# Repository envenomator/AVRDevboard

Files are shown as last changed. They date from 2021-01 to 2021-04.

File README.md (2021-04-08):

I bought the book 'Make: AVR Programming - by Elliot Williams' and soon got fed up breadboarding the experiments.
So I created an PCB-based development board for Atmega328p, with basics like 

8x LED on PB0-7
LDR / Potmeter
Servo header / servo power selector 
Two pushbuttons, one at each INT0/1
I2C header 
Serial header 

Several jumpers, to make optimal use of pins.

Selections via jumpers:
1) Use either crystal or LEDs on PB6/7
2) Use either LDR or Potmeter at PC0
3) Use either Servo or LED at PB1 / T1 16-bit timer OC1A
4) Use either VCC voltage for servo, or seperately supplied voltage

PINs available for
1) I2C
2) Serial GND/TX/RX
3) INT0/INT1

Photo shows an earlier PCB with switched labels. Current gerbers are correct and have been printed correctly at JLCPCB.

Enjoy experimenting!

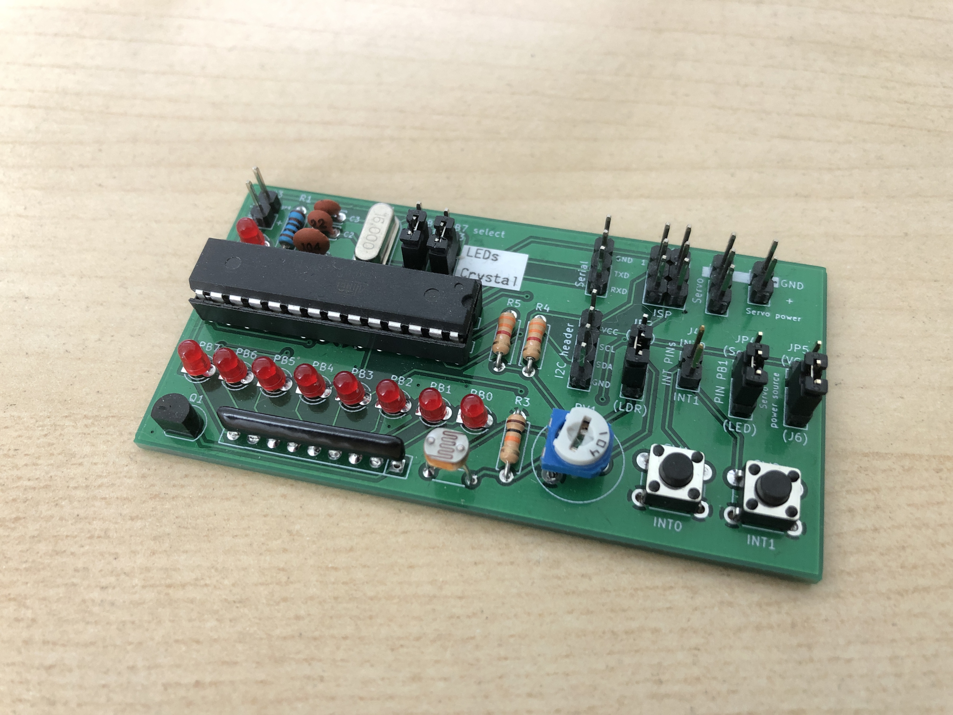
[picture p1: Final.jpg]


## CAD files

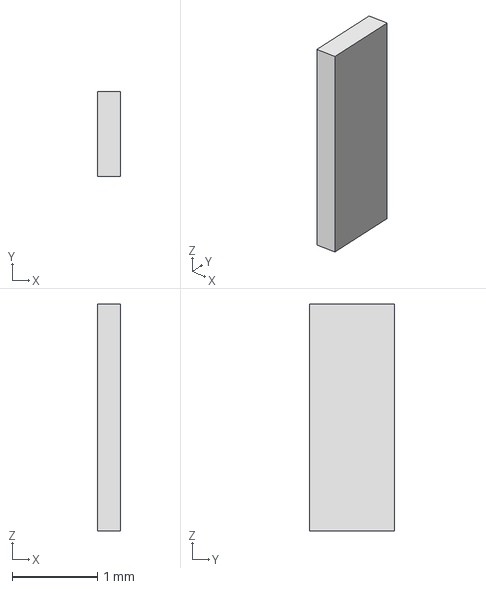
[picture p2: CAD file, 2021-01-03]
eec.models/Texas_Instruments_-_OPA37GP.step
0.27 x 1 x 2.66 mm

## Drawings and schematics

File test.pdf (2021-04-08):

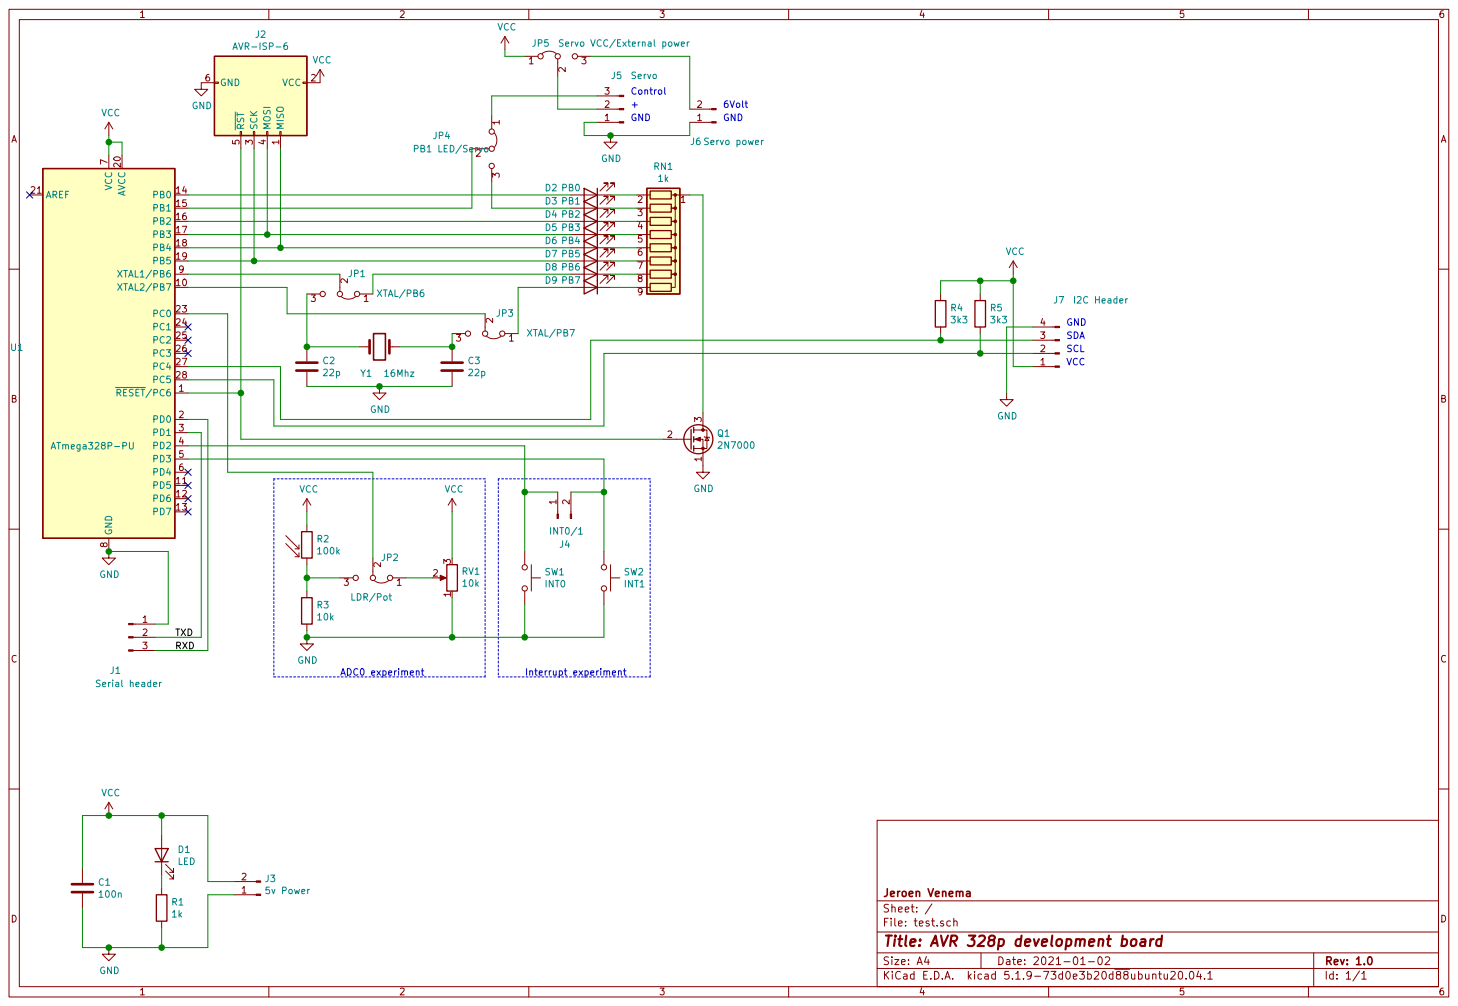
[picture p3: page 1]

TXD
J1 Serial header VCC GND

File: test.sch Sheet: / Jeroen Venema

Id: 1/1 Title: AVR 328p development board

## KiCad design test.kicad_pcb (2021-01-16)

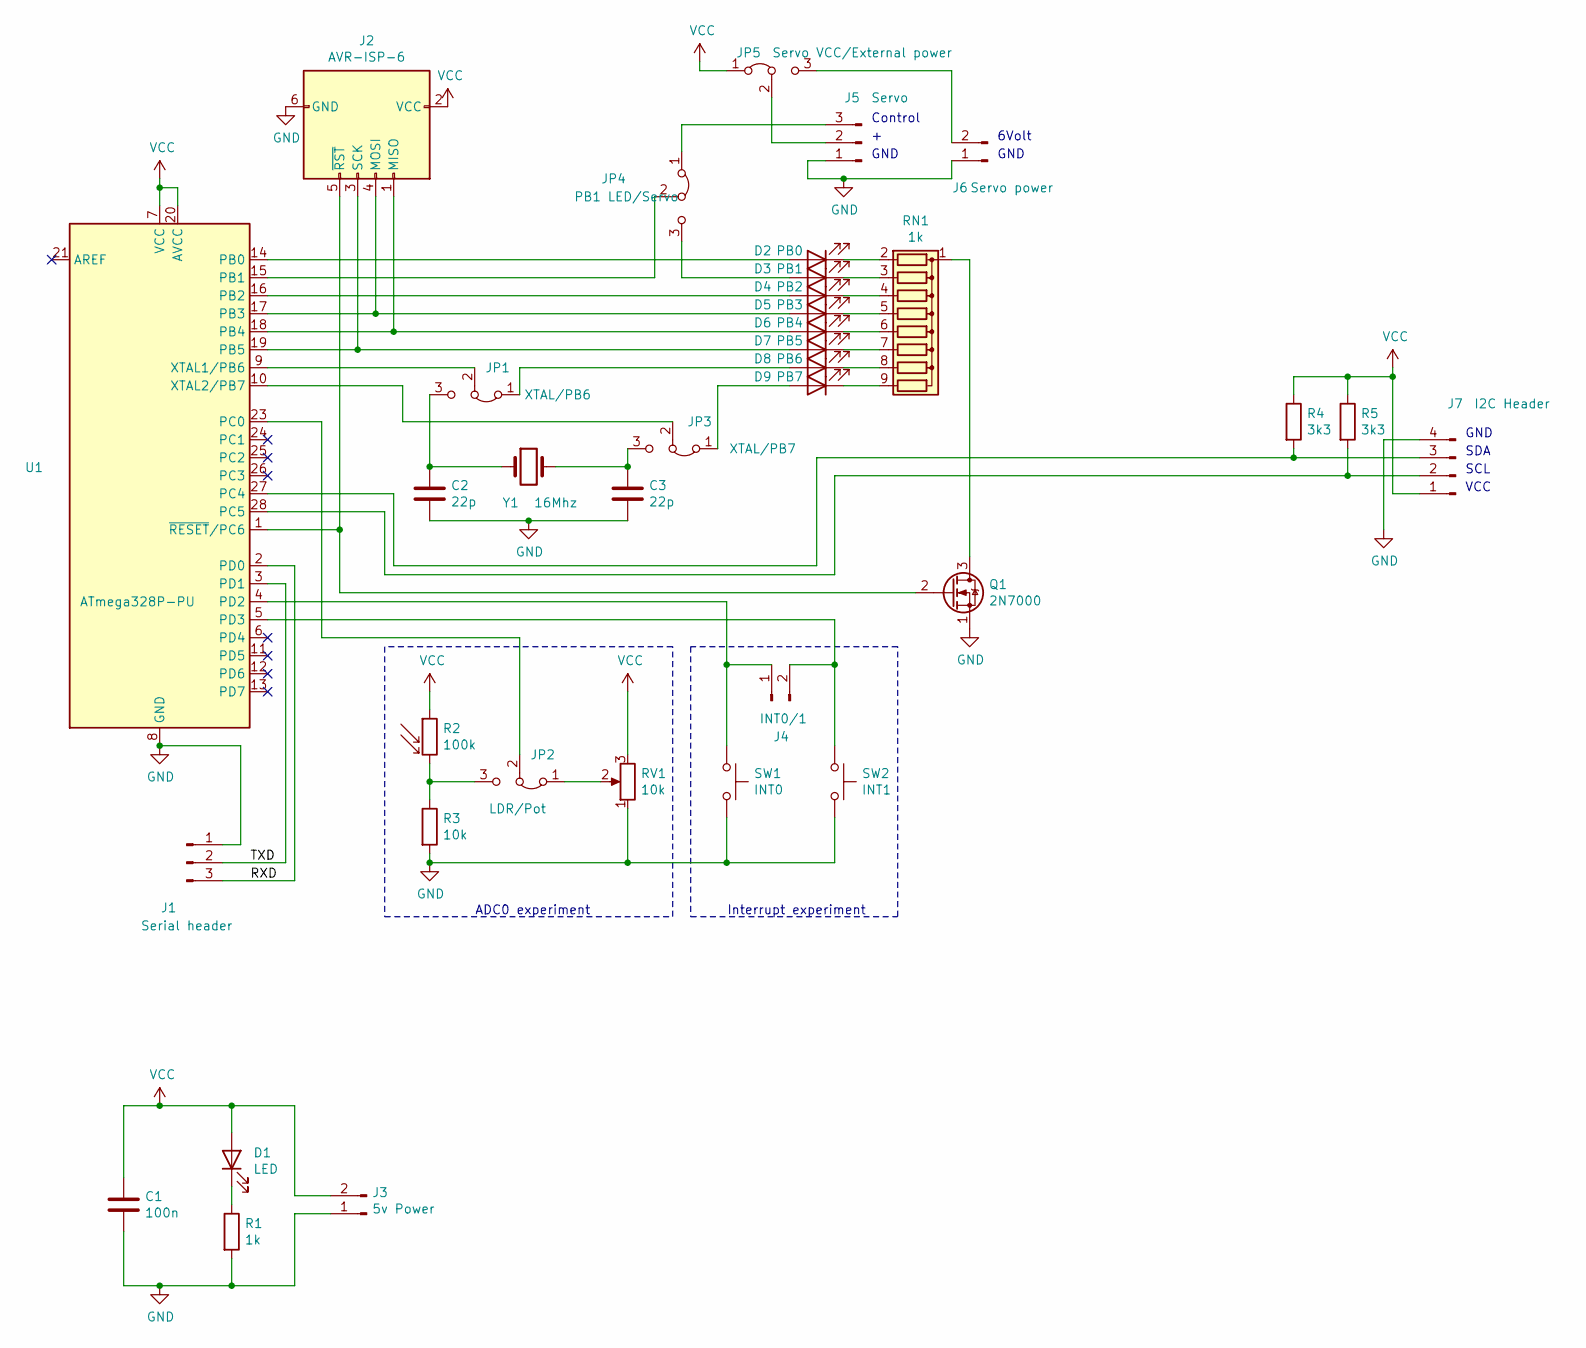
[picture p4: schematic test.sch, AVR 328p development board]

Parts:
C1: 100n; C_Disc_D3.4mm_W2.1mm_P2.50mm
C2, C3: 22p; C_Disc_D3.4mm_W2.1mm_P2.50mm
D1: LED; LED_D3.0mm
D2: PB0; LED_D3.0mm
D3: PB1; LED_D3.0mm
D4: PB2; LED_D3.0mm
D5: PB3; LED_D3.0mm
D6: PB4; LED_D3.0mm
D7: PB5; LED_D3.0mm
D8: PB6; LED_D3.0mm
D9: PB7; LED_D3.0mm
J1: Serial header; PinHeader_1x03_P2.54mm_Vertical
J2: AVR-ISP-6; PinHeader_2x03_P2.54mm_Vertical
J3: 5v Power; PinHeader_1x02_P2.54mm_Vertical
J4: INT0/1; PinHeader_1x02_P2.54mm_Vertical
J5: Servo; PinHeader_1x03_P2.54mm_Vertical
J6: Servo power; PinHeader_1x02_P2.54mm_Vertical
J7: I2C Header; PinHeader_1x04_P2.54mm_Vertical
JP1: XTAL/PB6; PinHeader_1x03_P2.54mm_Vertical
JP2: LDR/Pot; PinHeader_1x03_P2.54mm_Vertical
JP3: XTAL/PB7; PinHeader_1x03_P2.54mm_Vertical
JP4: PB1 LED/Servo; PinHeader_1x03_P2.54mm_Vertical
JP5: Servo VCC/External power; PinHeader_1x03_P2.54mm_Vertical
Q1: 2N7000; TO-92_Inline
R1: 1k; R_Axial_DIN0207_L6.3mm_D2.5mm_P7.62mm_Horizontal
R2: 100k; R_Axial_DIN0204_L3.6mm_D1.6mm_P5.08mm_Horizontal
R3: 10k; R_Axial_DIN0207_L6.3mm_D2.5mm_P7.62mm_Horizontal
R4, R5: 3k3; R_Axial_DIN0207_L6.3mm_D2.5mm_P7.62mm_Horizontal
RN1: 1k; R_Array_SIP9
RV1: 10k; Potentiometer_Piher_PT-10-V05_Vertical
SW1: INT0; SW_PUSH_6mm
SW2: INT1; SW_PUSH_6mm
U1: ATmega328P-PU; DIP-28_W7.62mm
Y1: 16Mhz; Crystal_HC18-U_Vertical

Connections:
/RXD: J1.3, U1.2 (PD0)
/TXD: J1.2, U1.3 (PD1)
GND: C1.2, C2.2, C3.2, J1.1, J2.6 (GND), J3.1, J5.1, J6.1, J7.4, Q1.1 (S), R1.2, R3.2, RV1.1, SW1.2, SW2.2, U1.8 (GND), U1.22 (GND)
unnamed: C2.1, JP1.3 (B), Y1.1
unnamed: C3.1, JP3.3 (B), Y1.2
unnamed: D1.1 (K), R1.1
unnamed: D2.1 (K), RN1.2 (R1)
unnamed: D2.2 (A), U1.14 (PB0)
unnamed: D3.1 (K), RN1.3 (R2)
unnamed: D3.2 (A), JP4.3 (B)
unnamed: D4.1 (K), RN1.4 (R3)
unnamed: D4.2 (A), U1.16 (PB2)
unnamed: D5.1 (K), RN1.5 (R4)
unnamed: D5.2 (A), J2.4 (MOSI), U1.17 (PB3)
unnamed: D6.1 (K), RN1.6 (R5)
unnamed: D6.2 (A), J2.1 (MISO), U1.18 (PB4)
unnamed: D7.1 (K), RN1.7 (R6)
unnamed: D7.2 (A), J2.3 (SCK), U1.19 (PB5)
unnamed: D8.1 (K), RN1.8 (R7)
unnamed: D8.2 (A), JP1.1 (A)
unnamed: D9.1 (K), RN1.9 (R8)
unnamed: D9.2 (A), JP3.1 (A)
unnamed: J2.5 (~RST), Q1.2 (G), U1.1 (~RESET~/PC6)
unnamed: J4.1, SW1.1, U1.4 (PD2)
unnamed: J4.2, SW2.1, U1.5 (PD3)
unnamed: J5.2, JP5.2 (C)
unnamed: J5.3, JP4.1 (A)
unnamed: J6.2, JP5.3 (B)
unnamed: J7.2, R5.2, U1.28 (PC5)
unnamed: J7.3, R4.2, U1.27 (PC4)
unnamed: JP1.2 (C), U1.9 (XTAL1/PB6)
unnamed: JP2.1 (A), RV1.2
unnamed: JP2.2 (C), U1.23 (PC0)
unnamed: JP2.3 (B), R2.2, R3.1
unnamed: JP3.2 (C), U1.10 (XTAL2/PB7)
unnamed: JP4.2 (C), U1.15 (PB1)
unnamed: Q1.3 (D), RN1.1 (common)
VCC: C1.1, D1.2 (A), J2.2 (VCC), J3.2, J7.1, JP5.1 (A), R2.1, R4.1, R5.1, RV1.3, U1.7 (VCC), U1.20 (AVCC)

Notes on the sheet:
ADC0 experiment
Interrupt experiment
Control
GND
6Volt
VCC
SCL
SDA

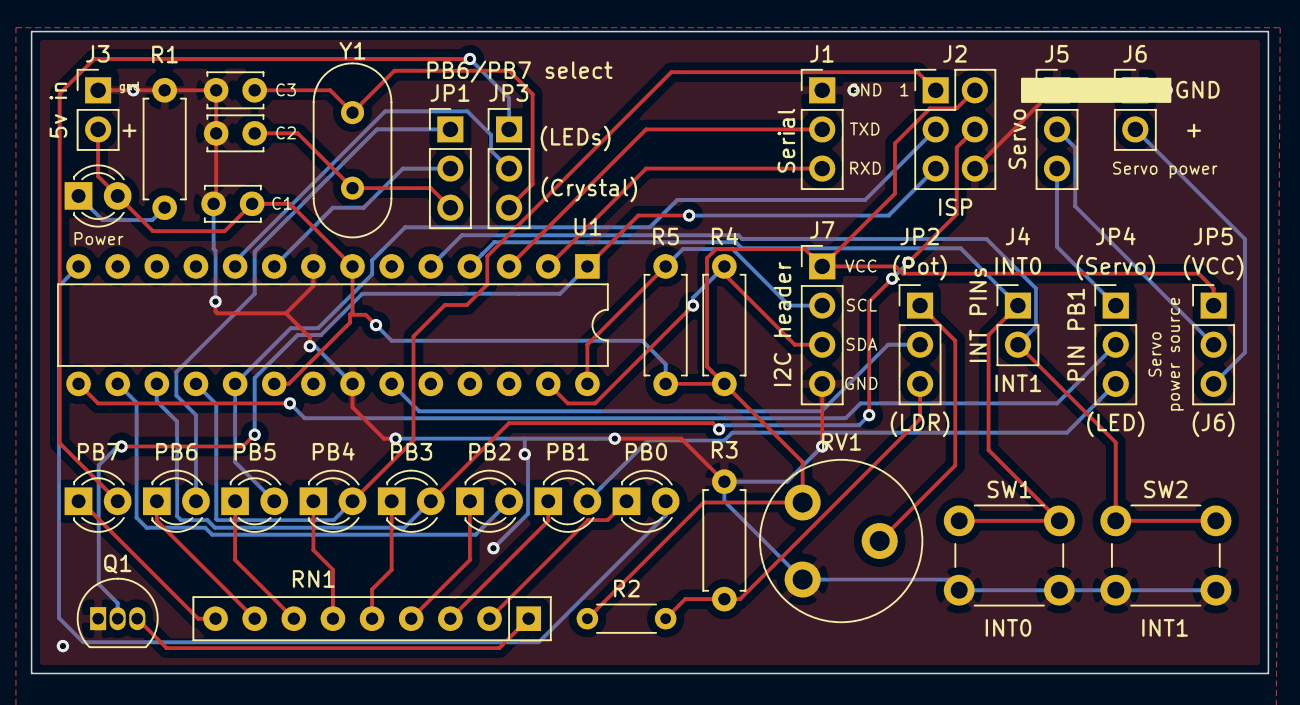
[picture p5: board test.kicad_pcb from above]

Board: 2 copper layers, 80.3 x 41.7 mm, 36 parts (0 on the bottom side), 38 nets.

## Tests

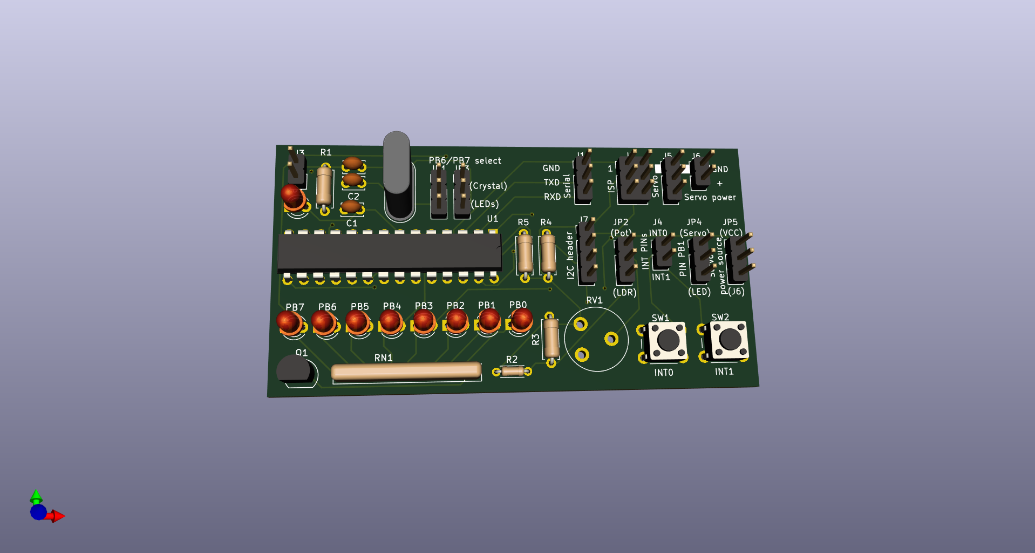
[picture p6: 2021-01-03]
test.png

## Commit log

2021-01-03 Board as sent to PCBWay
    [Texas_Instruments_-_OPA37GP.step, test.kicad_pcb, test.sch]
2021-01-03 Schema error in PD5 fixed, sent to JLCPCB
    [test-B_Cu.gbl, test-B_Mask.gbs, test-B_Paste.gbp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]
2021-01-08 Swapped crystal/LED text at JP1/JP3
    [test.kicad_pcb]
2021-01-16 Created new Gerbers
    [test-B_Cu.gbr, test-B_Mask.gbr, test-B_Paste.gbr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]
2021-01-16 Saved PCB
    [test.kicad_pcb]
2021-04-08 Photo and pdf schematic

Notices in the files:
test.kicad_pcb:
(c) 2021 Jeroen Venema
